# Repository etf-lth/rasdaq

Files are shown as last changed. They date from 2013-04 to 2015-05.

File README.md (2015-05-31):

# Rasdaq: Raspberry Pi Data Acquisition

Rasdaq is a 8-channel 16-bit high-speed ADC solution using the Raspberry Pi, with current measurement adapters.
Rasdaq was developed by ETF (The Student’s Association for Applied Electronics at the Faculty of Engineering (LTH), Lund University, Sweden) for
academic research in power efficiency of graphic accelerators (GPUs).

An illustrated introduction is available here: http://etf.nu/projects/rasdaq

User manual and schematics are available in `doc/`.

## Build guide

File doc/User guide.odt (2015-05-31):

Rasdaq Measurement System

by

ETF LTH

v1.0

Hardware

Kit includes:

1. 1x Rasdaq
2. 1x Power supply 5V 2A
3. 1x Power Measurement Adapter
4. 2x Dummy plugs

Rasdaq

The Rasdaq system is based on a Raspberry pi module, with a extension board containing one TI ADS8568 and one Atmega88 for accurate sample rate.

The ADS8568 contains eight 16-bit channels that can be simultaneously sampled at 500Khz with an input swing from -12V to 12V.

Because of restrictions in the Raspberrys non deterministic execution it's not possible to sample at full speed, the maximum sample rate that is stable is 200Khz for 1-8 channels. Higher rates might work but tends to stall the ADC from operating after first run. This might be fixable in software but there are no timetable for this.

The Rasdaq has four connection slots, named A-D each connector has two ad channels connected to it. There is also power supplied in this connector to drive external converters.

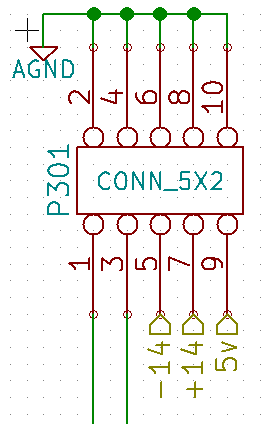
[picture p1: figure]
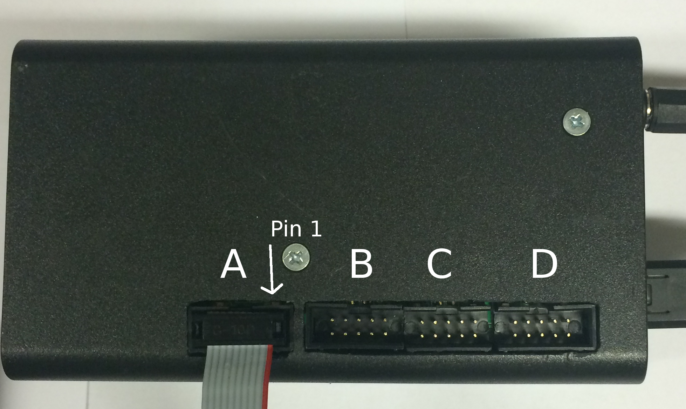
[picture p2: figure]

Power Supply

If this needs to be replaced make sure the polarity of the connector is correct, and that is is of good quality, to large swings in the input voltage might affect the accuracy of the measurements

Positive in center and negative on outer ring.

Power Measurement Adapter

This box connects to the rasdaq and use two channel to measure both the current and the voltage.

It measures the current by using a small resistor (0.05ohm) and amplifies the voltage drop 50 times.

Warning: The plug to Tablet need to be positioned the right way, RED to RED. Failure to do this might destroy the battery.

The connector is polarized so that it should only fit in one way but the leads might still touch if it's tested.

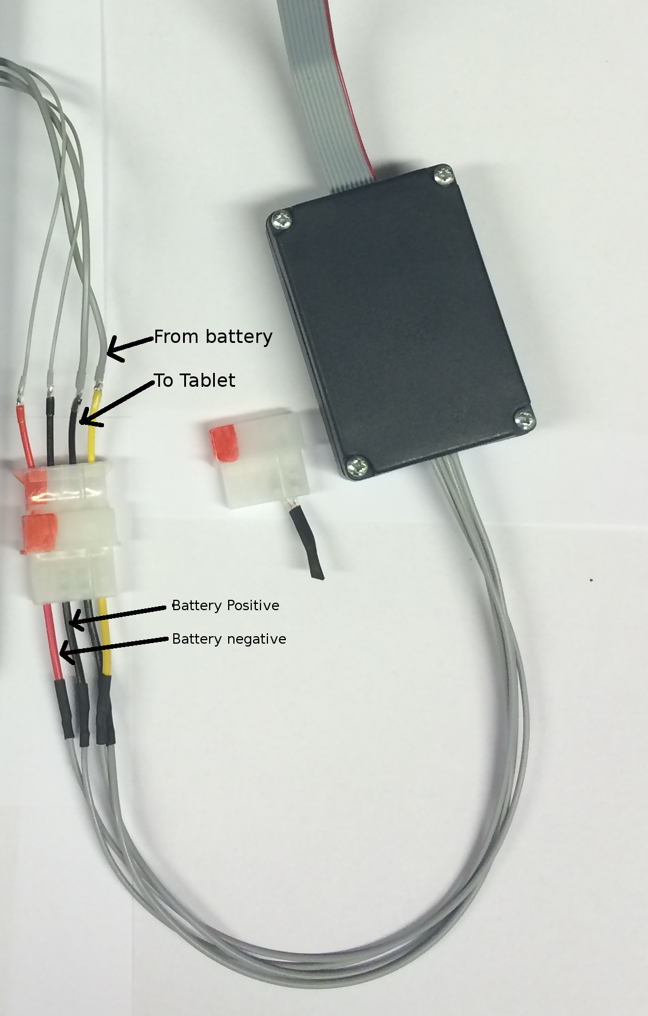
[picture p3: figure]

Dummy plugs

Measuring the current requires the path from the battery to the tablet to be broken, this means the the tablet only function when connected to the Rasdaq.

By using the dummy plugs the connection is made again and the tablet can be used as normal.

This plug is also useful when charging the tablets.

Warning: This plug need to be positioned the right way, RED to RED. Failure to do this might destroy the battery.

The connector is polarized so that it should only fit in one way but the leads might still touch if it's tested.

Software

Rasdaq

The Rasdaq connects through Ethernet and expects to get an IP address from DHCP. To start and downloading measurements SSH is used.

Log on to the rasdaq with

User: root

Password: toor

For doing measurements run the program rdqtool

# rdqtool -h

rdqtool (c) Fredrik Ahlberg, 2013 <fredrik@etf.nu>

Options: -q quiet

-c[n] number of channels, 1..8, default: 8

-r[fs] sample rate in Hz, 1..500000, default: 10000

-b[n] maximum buffer size in tuples, 1..8192

-o[fn] output filename, default: stdout

-n[ns] Stop after n samples, default: run forever

This gives a number of choices on how to to the measurements.

The most important parts are number of channels, sample rate an output filename.

The channels are divided as following

Slot A CH 1,2

Slot B CH 3.4

Slot C CH 5,6

Slot D CH 7.8

Number of channels always starts from channel 1 and forward. It is for example not possible to only sample CH 8.

Example:

rdqtool -c 2 -r 100000 -o test.bin -n 10000

Samples takes 10000 samples in 100Khz from CH 1,2 and saves it to the file test.bin

It is recommended to save the measurements to the internal memory and then download the file as the Raspberry have limited Ethernet capability while it's running the ADC

Computer

The files created from the Rasdaq save the samples as signed 16-bit in the channel sequence.

So for two channels the file looks as following.

CH1_1,CH2_1, CH1_2,CH2_2 and so on.

Example octave script to plot the measured Current and Voltage

fid = fopen('test.bin');
% Open file

adc = fread(fid, [2, inf], '*int16');
% Read file with 2 Channels

fclose(fid);

% sample rate [Hz]

fs = 100000.0;

% calculate number of samples read

samples = size(adc, 2);

% create time vector

t = linspace(0, samples/fs, samples);

% recalculate raw readings as voltage.

% the preamplifiers invert the measured voltages.

adc = double(adc);

adc = -adc * 12.0/32768.0;

% calculate current from voltage (shut resistance = 50 mohm, 0.05% tol, 50 V/V gain)

ch0 = adc(1, :) / (0.05 * 50);

% battery voltage on channel 1

ch1 = adc(2, :);

% apply a low-pass filter at 1kHz

fc = 1000.0;

[b,a] = butter(2, fc/fs);

ch0 = filter(b, a, ch0);

ch1 = filter(b, a, ch1);

% calculate power

ptot = ch0 .* ch1;

% plot

close all

clf

figure(1)

hold on

plot(t, ch1, 'r')

plot(t, ch0, 'g')

plot(t, ptot, 'b')

xlabel('Time [s]')

legend('Battery Voltage [V]', 'Battery Current [A]', 'Power [W]')

Taking samples

1. Connect Rasdaq to Ethernet
2. Connect power measurement box
3. Connect Tablet to power measurement box,

Make sure the connector is the correct way, Red to red

4. Use ssh to connect to Rasdaq and start taking samples
5. Start demo on Tablet
6. When demo done stop program on Rasdaq and download data.

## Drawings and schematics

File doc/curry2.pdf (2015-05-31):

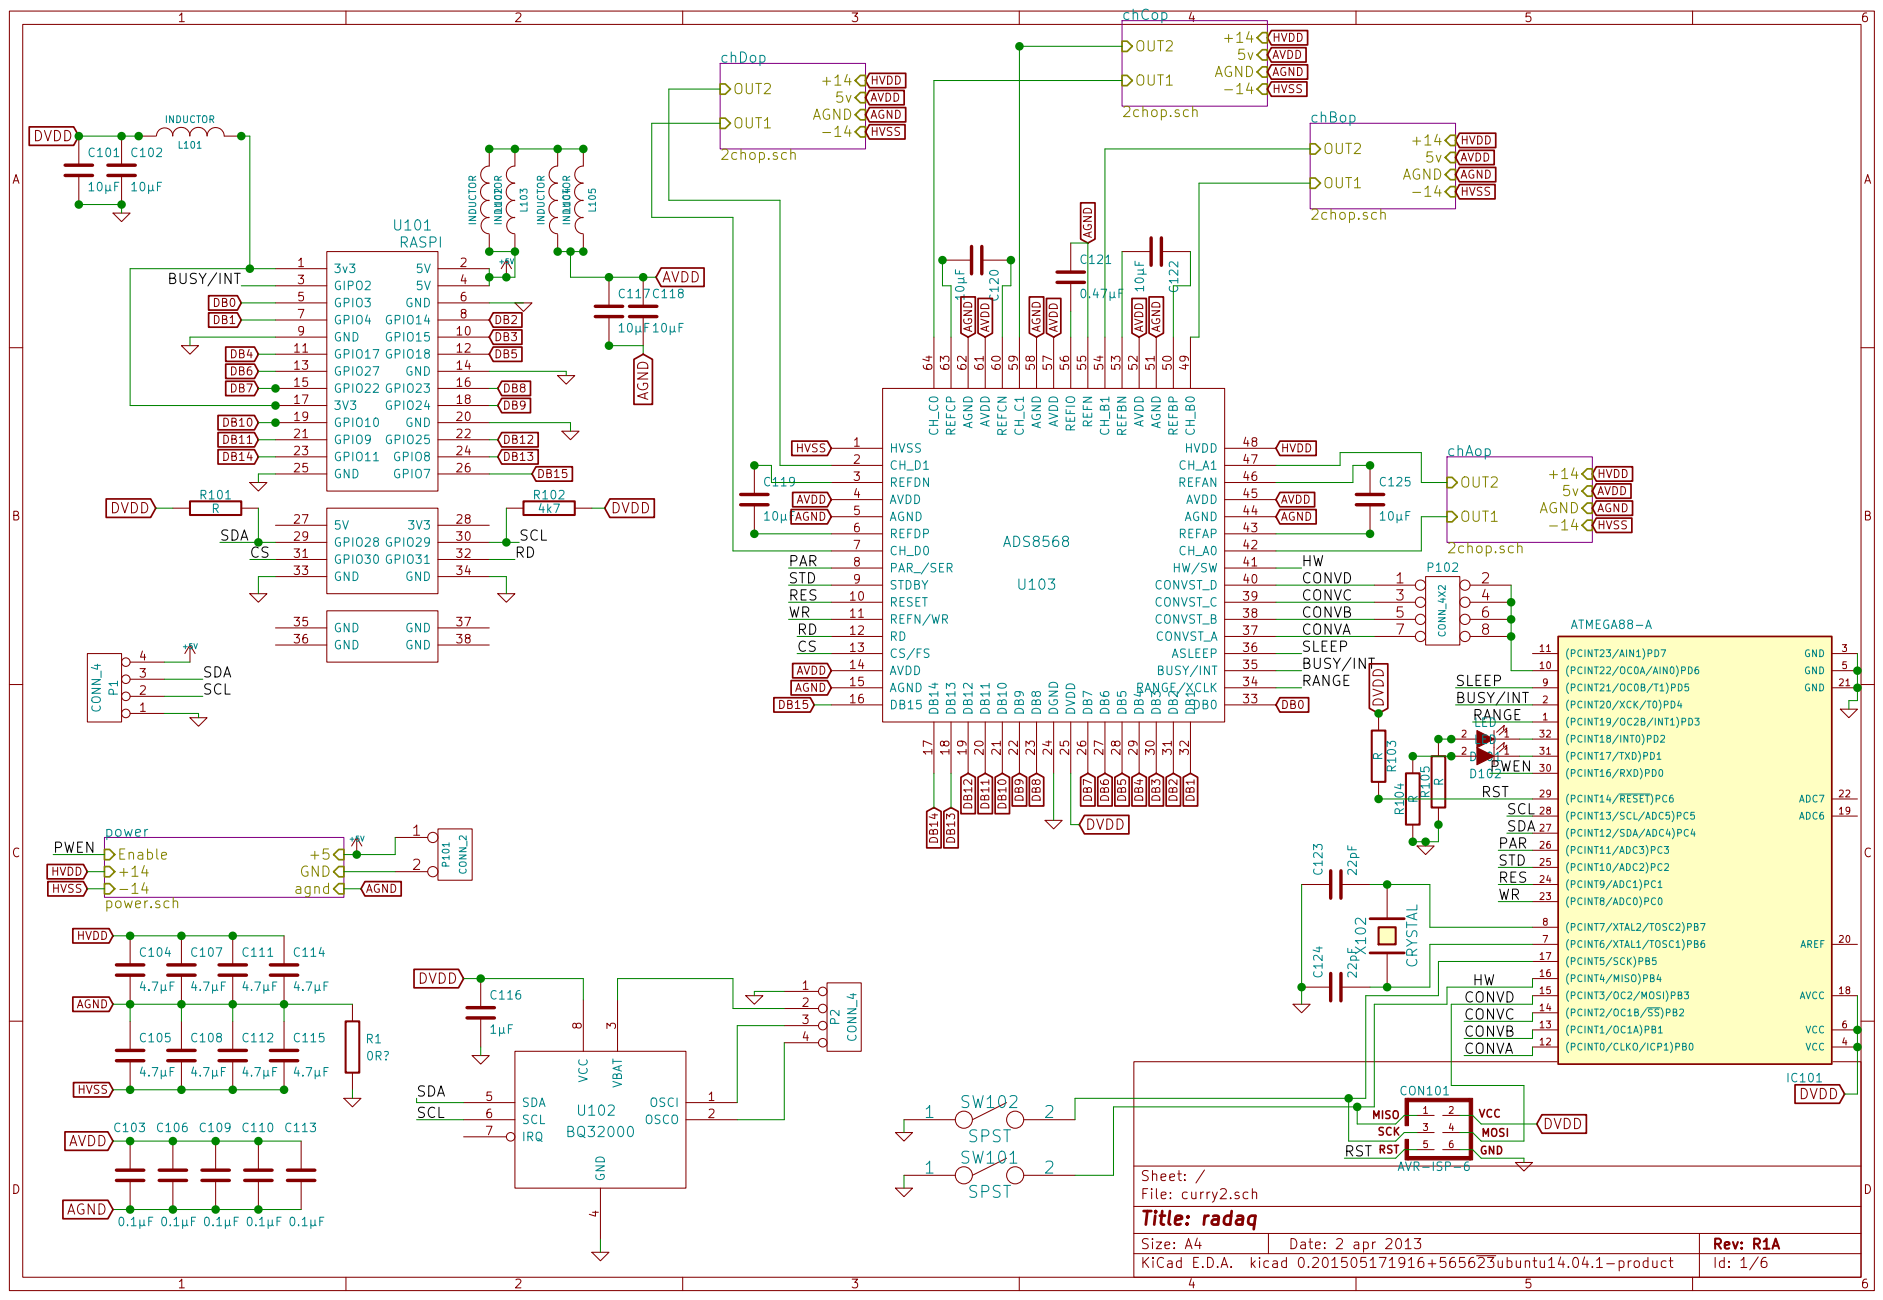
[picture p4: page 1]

10µF power power.sch Enable +14

CONVC 3 | 4
CONVB 5 | 6
CONVA 7 | 8

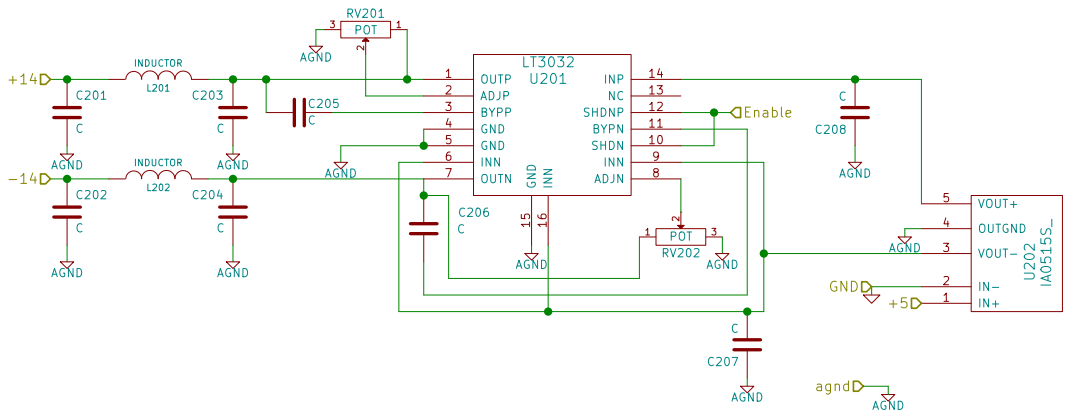
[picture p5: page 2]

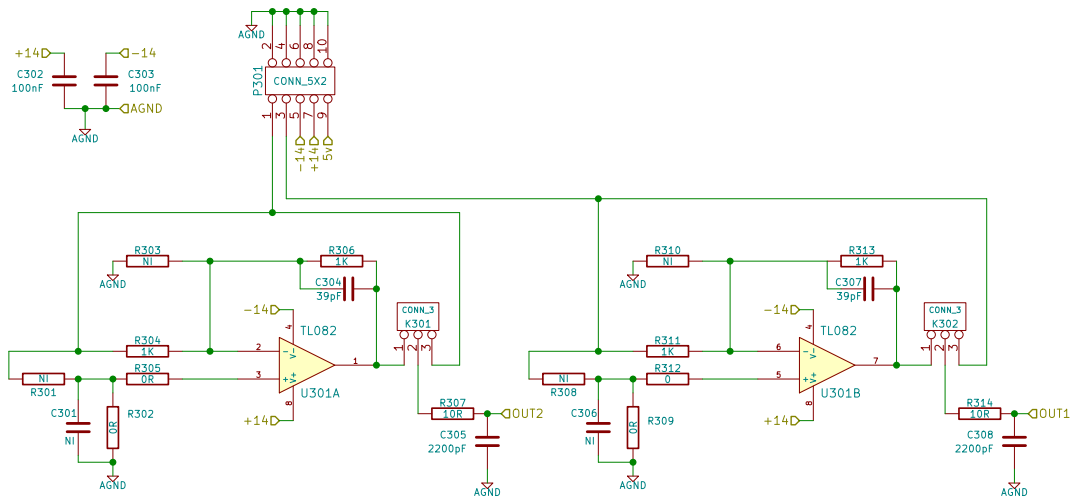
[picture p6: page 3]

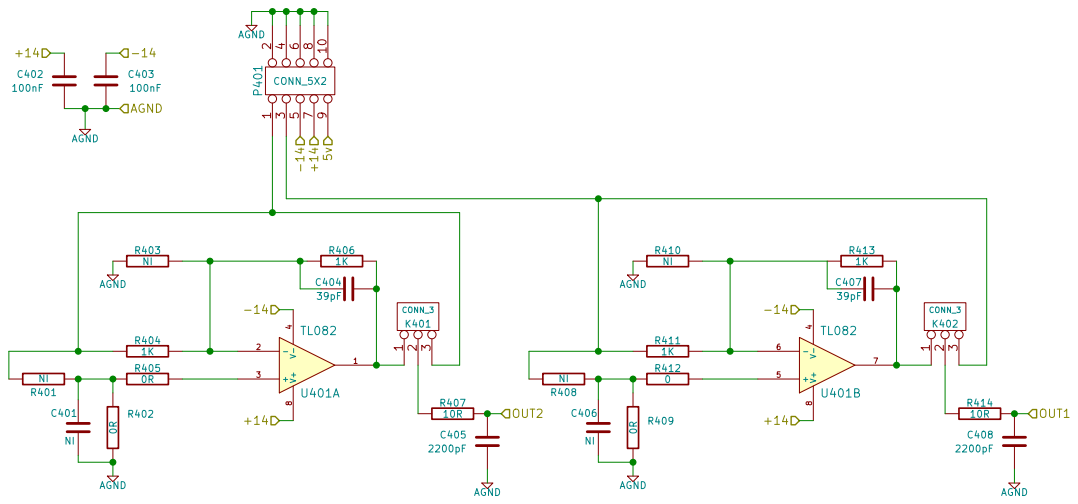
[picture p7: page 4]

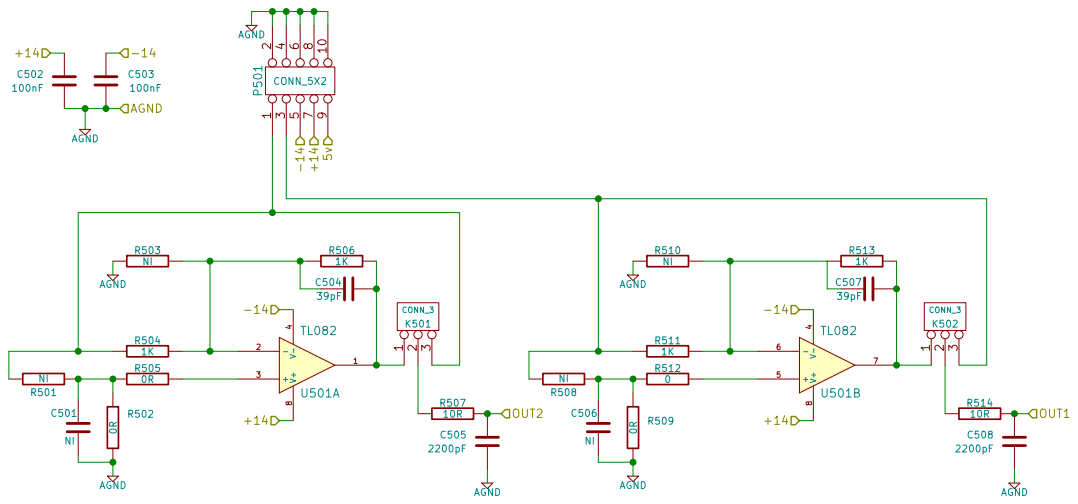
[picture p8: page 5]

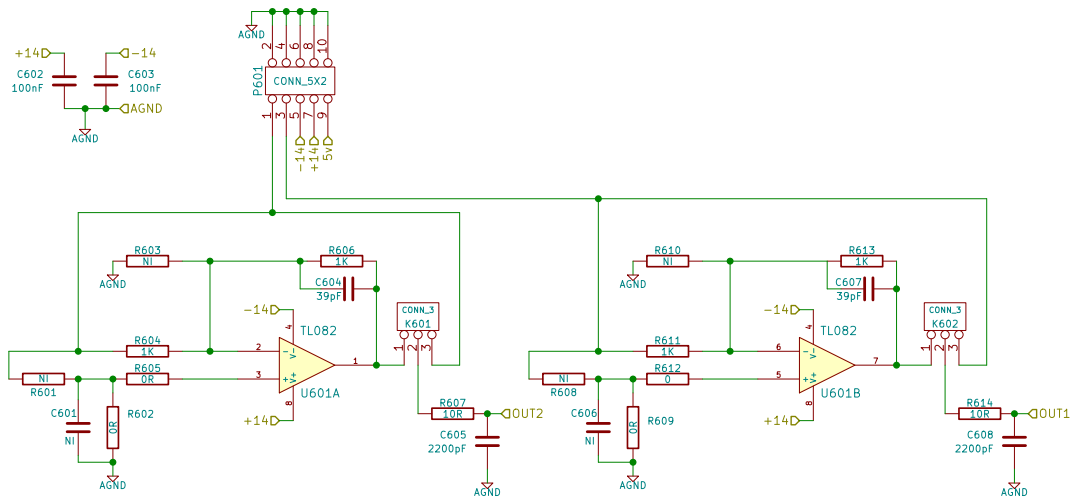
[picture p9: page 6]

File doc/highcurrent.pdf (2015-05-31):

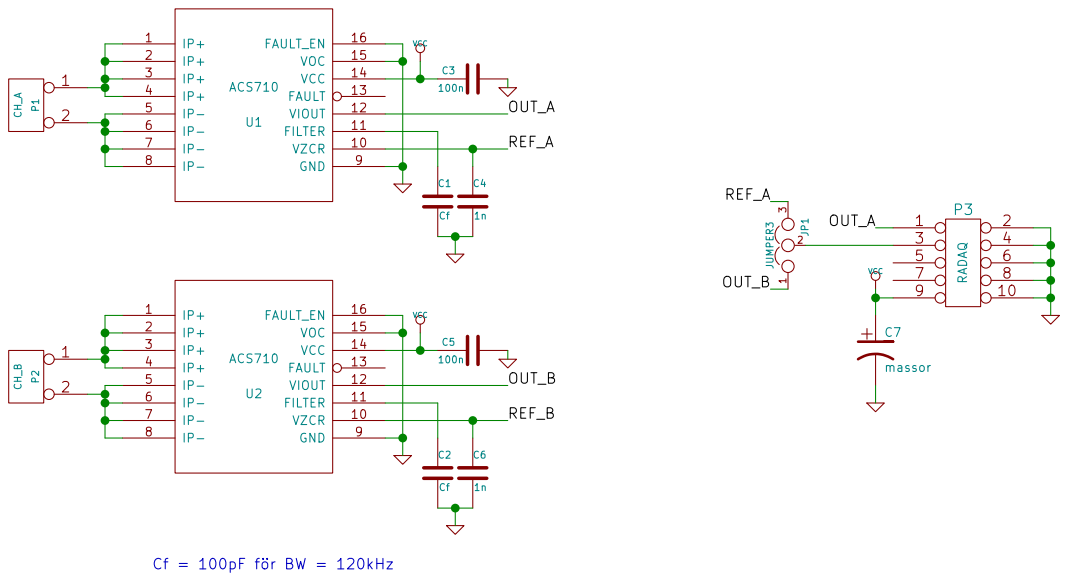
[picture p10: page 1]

File: highcurrent.sch Sheet: /
Id: 1/1 Title: High-current Sensor

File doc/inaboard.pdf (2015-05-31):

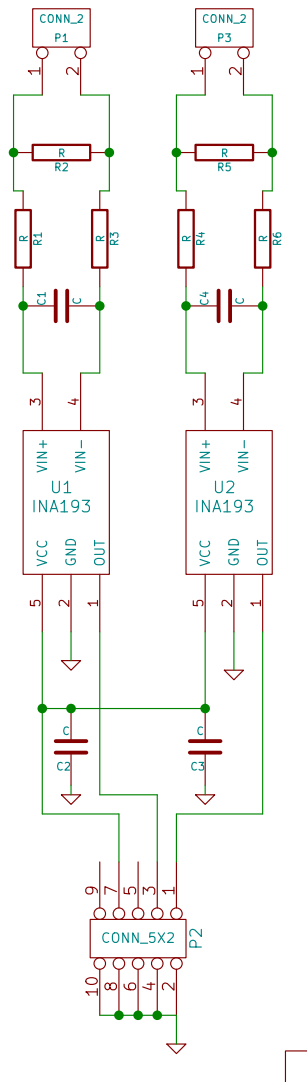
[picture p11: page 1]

1 GND
Id: 1/1 Title: File: inaboard.sch Sheet: / OUT

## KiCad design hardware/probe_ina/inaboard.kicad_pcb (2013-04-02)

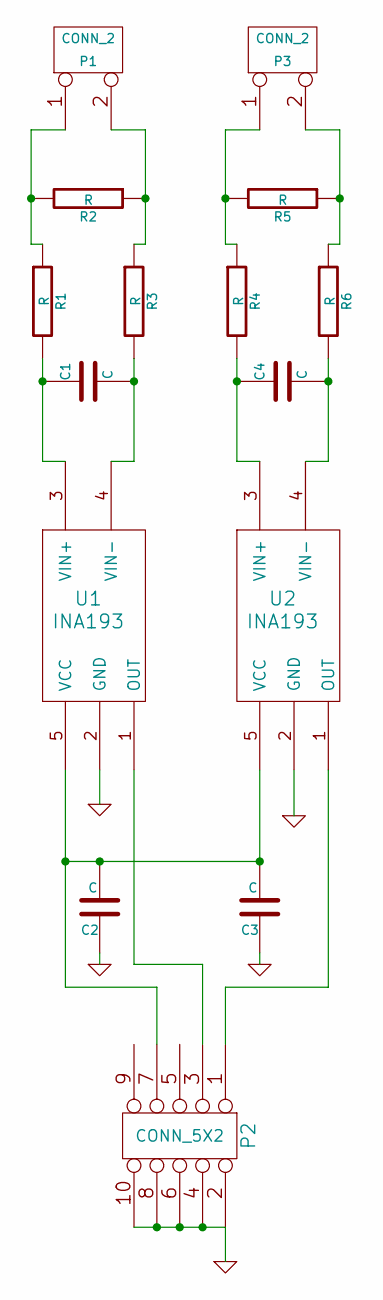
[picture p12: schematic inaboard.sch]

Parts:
C1, C2, C3, C4: C
P1, P3: CONN_2
P2: CONN_5X2
R1, R2, R3, R4, R5, R6: R
U1, U2: INA193

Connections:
GND: C2.1, C3.1, P2.2, P2.4, P2.6, P2.8, P2.10, U1.2 (GND), U2.2 (GND)
unnamed: C2.2, C3.2, P2.7, U1.5 (VCC), U2.5 (VCC)
unnamed: C4.1, R4.2, U2.3 (VIN+)
unnamed: P2.3, U1.1 (OUT)
unnamed: P2.1, U2.1 (OUT)
unnamed: P3.1, R4.1, R5.2
unnamed: P1.1, R1.1, R2.2
unnamed: P1.2 (PM), R2.1, R3.1
unnamed: P3.2 (PM), R5.1, R6.1
unnamed: C1.2, R3.2, U1.4 (VIN-)
unnamed: C1.1, R1.2, U1.3 (VIN+)
unnamed: C4.2, R6.2, U2.4 (VIN-)

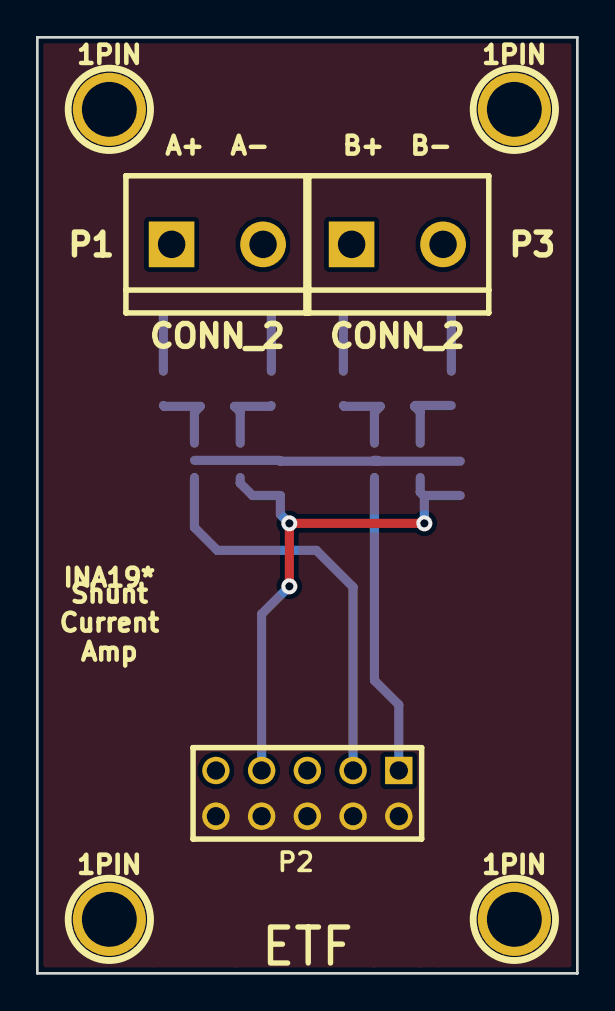
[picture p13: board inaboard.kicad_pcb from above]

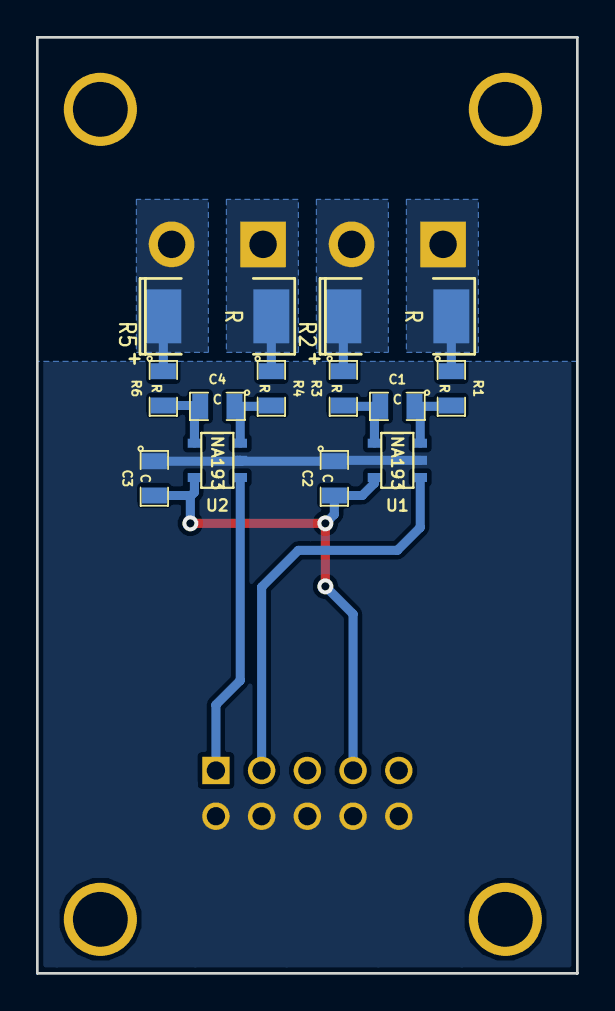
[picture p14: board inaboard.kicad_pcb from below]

Board: 2 copper layers, 30.0 x 52.0 mm, 19 parts (12 on the bottom side), 12 nets.

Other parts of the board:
1PIN, 1PIN#2, 1PIN#3, 1PIN#4: P***; 1pin

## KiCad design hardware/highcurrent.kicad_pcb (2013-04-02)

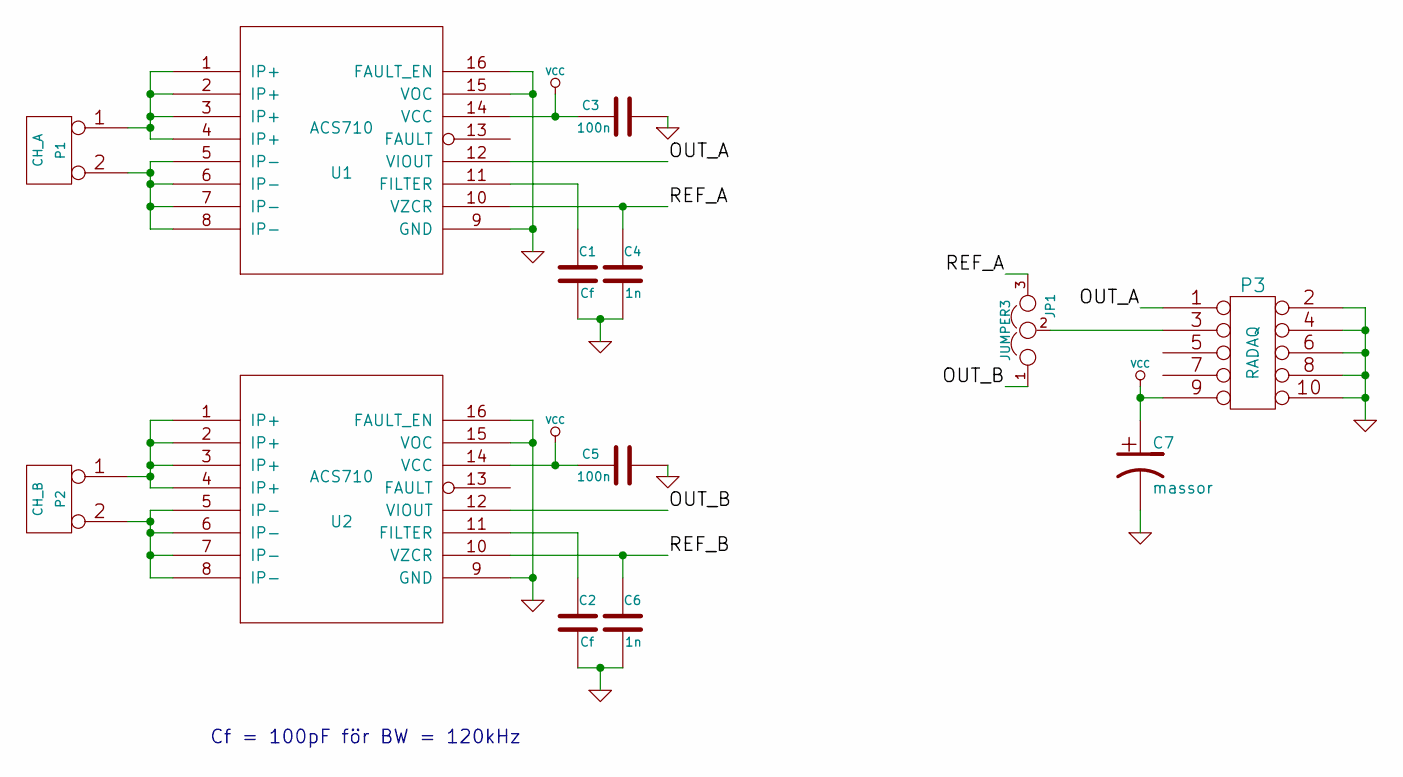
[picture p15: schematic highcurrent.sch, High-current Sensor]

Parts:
C1, C2: Cf
C3, C5: 100n
C4, C6: 1n
C7: massor
JP1: JUMPER3
P1: CH_A
P2: CH_B
P3: RADAQ
U1, U2: ACS710; MODULE

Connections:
/OUT_A: P3.1, U1.12 (VIOUT)
/OUT_B: JP1.1, U2.12 (VIOUT)
/REF_A: C4.1, JP1.3, U1.10 (VZCR)
/REF_B: C6.1, U2.10 (VZCR)
GND: C1.2, C2.2, C3.2, C4.2, C5.2, C6.2, C7.2, P3.2, P3.4, P3.6, P3.8, P3.10, U1.9 (GND), U1.15 (VOC), U1.16 (FAULT_EN), U2.9 (GND), U2.15 (VOC), U2.16 (FAULT_EN)
unnamed: C1.1, U1.11 (FILTER)
unnamed: JP1.2, P3.3
unnamed: C2.1, U2.11 (FILTER)
unnamed: P1.2 (PM), U1.5 (IP-), U1.6 (IP-), U1.7 (IP-), U1.8 (IP-)
unnamed: P1.1, U1.1 (IP+), U1.2 (IP+), U1.3 (IP+), U1.4 (IP+)
unnamed: P2.1, U2.1 (IP+), U2.2 (IP+), U2.3 (IP+), U2.4 (IP+)
unnamed: P2.2 (PM), U2.5 (IP-), U2.6 (IP-), U2.7 (IP-), U2.8 (IP-)
VCC: C3.1, C5.1, C7.1, P3.9, U1.14 (VCC), U2.14 (VCC)

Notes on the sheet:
Cf = 100pF för BW = 120kHz

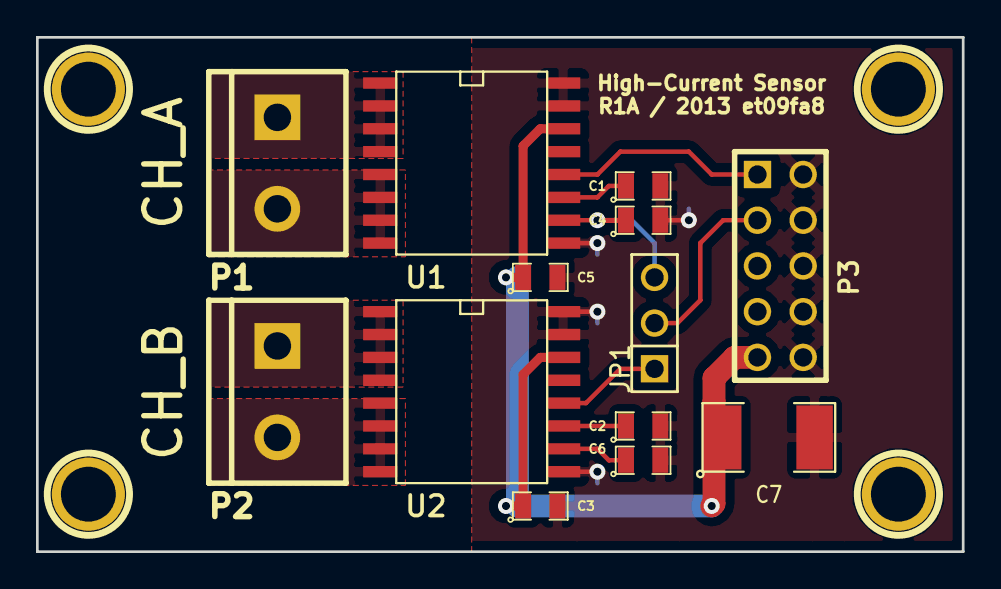
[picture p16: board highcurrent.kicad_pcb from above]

Board: 2 copper layers, 51.4 x 28.6 mm, 17 parts (0 on the bottom side), 13 nets.

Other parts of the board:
1PIN, 1PIN#2, 1PIN#3, 1PIN#4: P***; 1pin

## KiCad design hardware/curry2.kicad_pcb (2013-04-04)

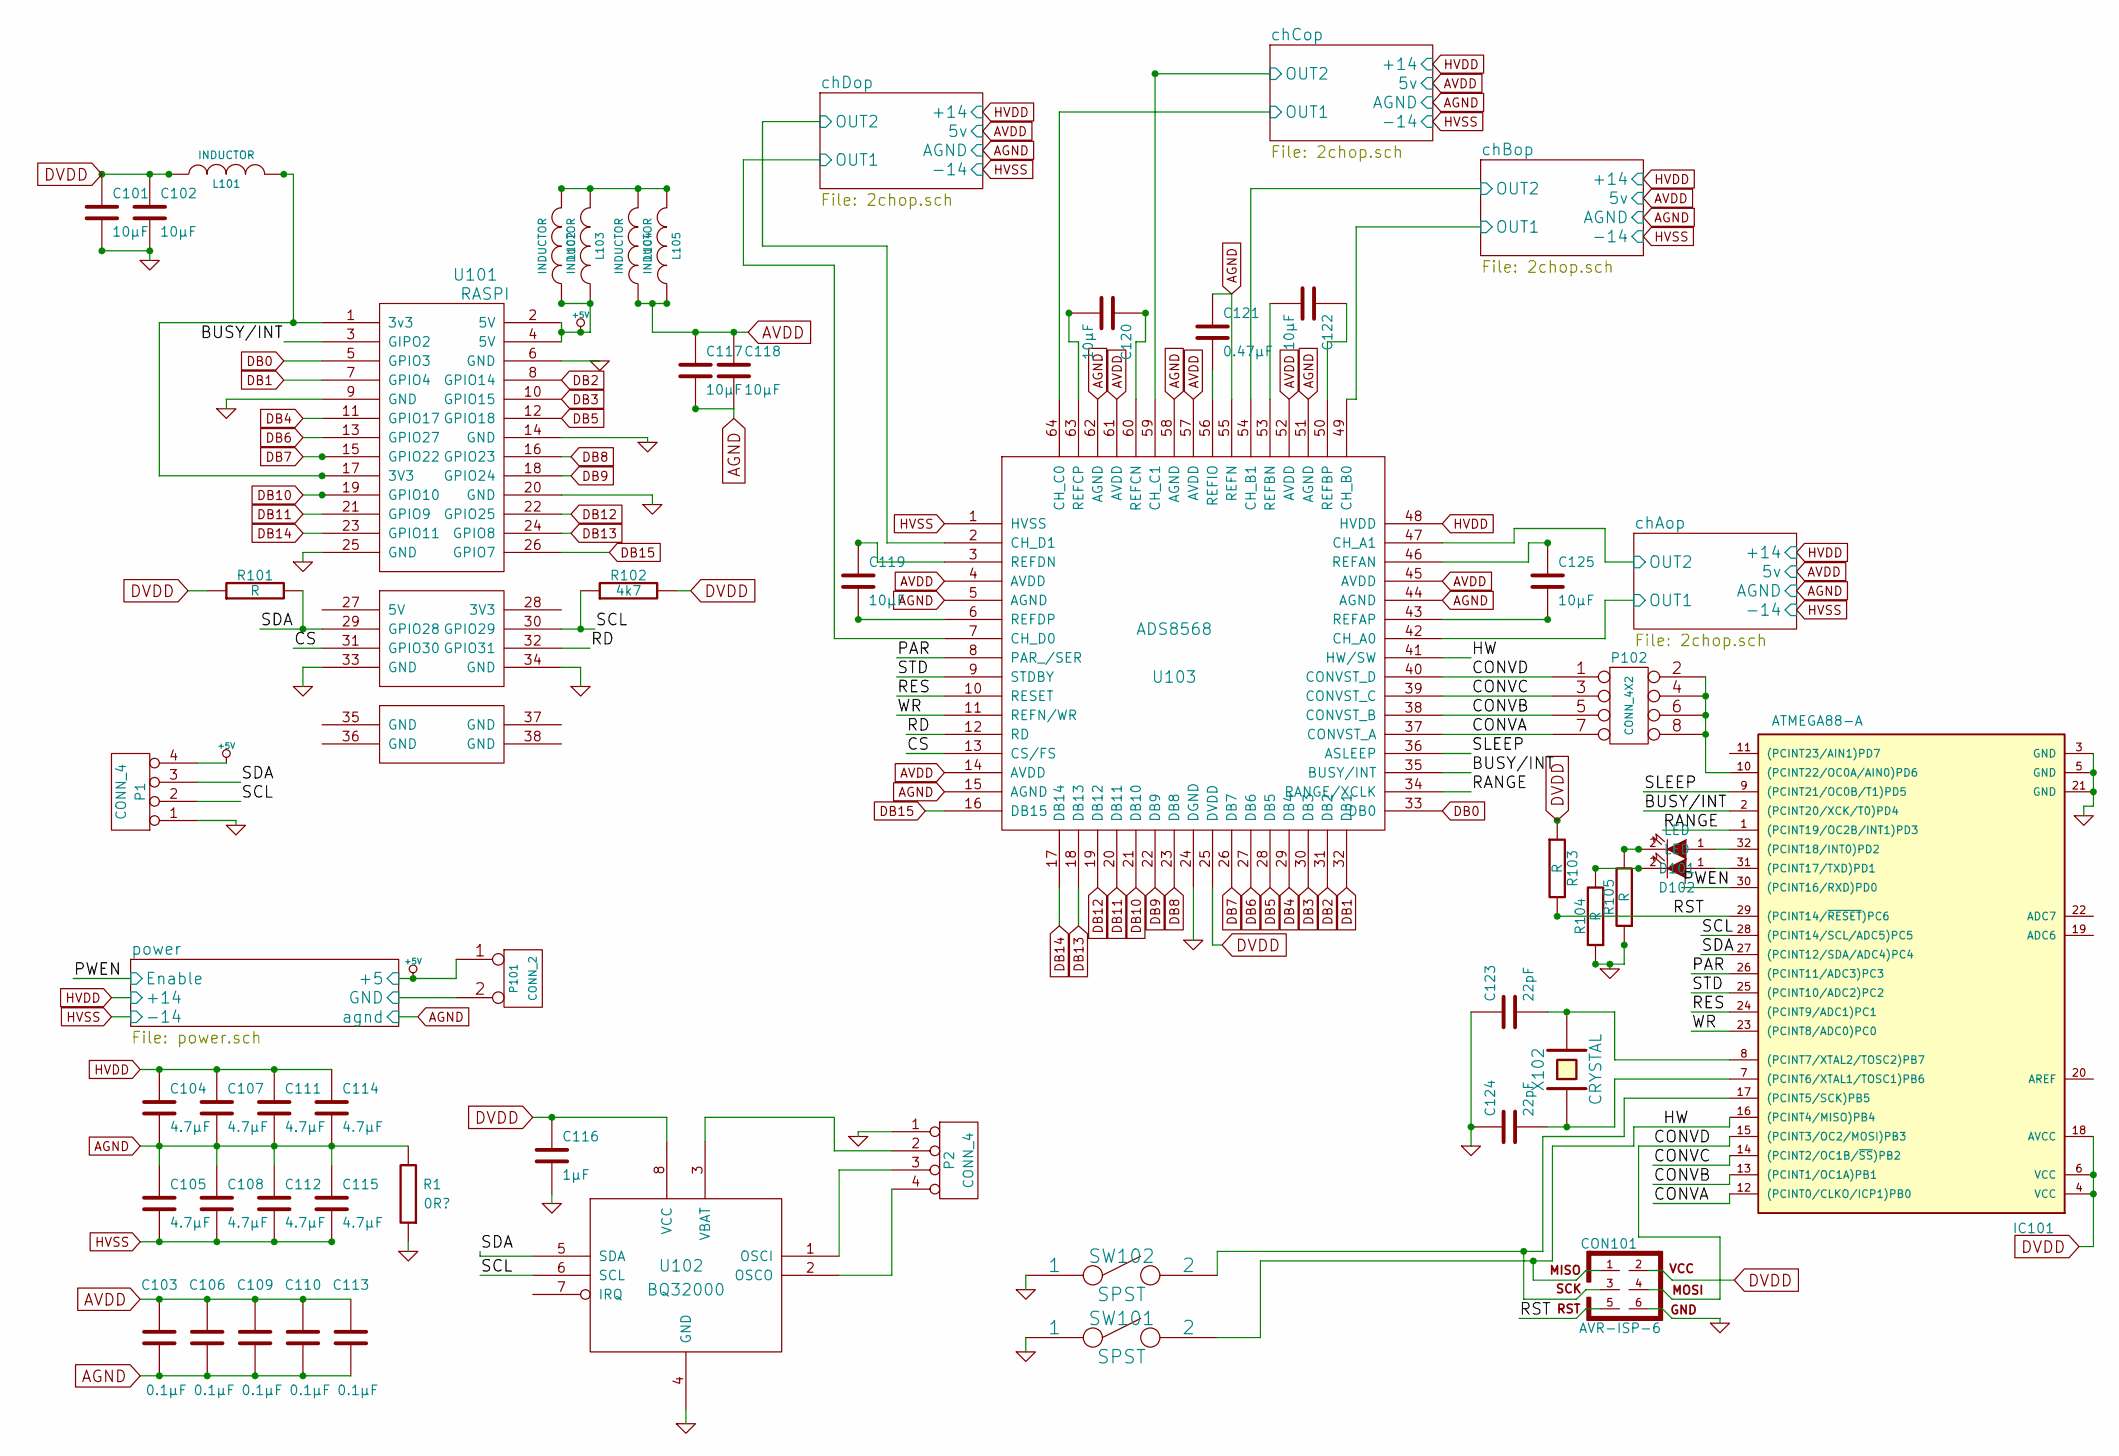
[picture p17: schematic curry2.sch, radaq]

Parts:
C101, C102, C117, C118, C119, C120, C122, C125: 10µF
C103, C106, C109, C110, C113: 0.1µF
C104, C105, C107, C108, C111, C112, C114, C115: 4.7µF
C116: 1µF
C121: 0.47µF
C123, C124: 22pF
CON101: AVR-ISP-6
D101, D102: LED
IC101: ATMEGA88-A; TQFP32
L101, L102, L103, L104, L105: INDUCTOR
P1, P2: CONN_4
P101: CONN_2
P102: CONN_4X2
R1: 0R?
R101, R103, R104, R105: R
R102: 4k7
SW101, SW102: SPST
U101: RASPI
U102: BQ32000
U103: ADS8568
X102: CRYSTAL

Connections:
+5V: L102.1, L103.1, P1.4, P101.1, U101.2 (5V), U101.4 (5V); also elsewhere on the board
/BUSY/INT: IC101.2 ((PCINT20/XCK/T0)PD4), U101.3 (GIPO2), U103.35 (BUSY/INT)
/CONVA: IC101.12 ((PCINT0/CLKO/ICP1)PB0), P102.7, U103.37 (CONVST_A)
/CONVB: IC101.13 ((PCINT1/OC1A)PB1), P102.5, U103.38 (CONVST_B)
/CONVC: IC101.14 ((PCINT2/OC1B/~SS~)PB2), P102.3, U103.39 (CONVST_C)
/CONVD: CON101.4, IC101.15 ((PCINT3/OC2/MOSI)PB3), P102.1, U103.40 (CONVST_D)
/CS: U101.31 (GPIO30), U103.13 (CS/FS)
/HW: CON101.1, IC101.16 ((PCINT4/MISO)PB4), SW101.2, U103.41 (HW/SW)
/PAR: IC101.26 ((PCINT11/ADC3)PC3), U103.8 (PAR_/SER)
/RANGE: IC101.1 ((PCINT19/OC2B/INT1)PD3), U103.34 (RANGE/XCLK)
/RD: U101.32 (GPIO31), U103.12 (RD)
/RES: IC101.24 ((PCINT9/ADC1)PC1), U103.10 (RESET)
/RST: CON101.5, IC101.29 ((PCINT14/~RESET~)PC6), R103.2
/SCL: IC101.28 ((PCINT14/SCL/ADC5)PC5), P1.2, R102.1, U101.30 (GPIO29), U102.6 (SCL)
/SDA: IC101.27 ((PCINT12/SDA/ADC4)PC4), P1.3, R101.2, U101.29 (GPIO28), U102.5 (SDA)
/SLEEP: IC101.9 ((PCINT21/OC0B/T1)PD5), U103.36 (ASLEEP)
/STD: IC101.25 ((PCINT10/ADC2)PC2), U103.9 (STDBY)
/WR: IC101.23 ((PCINT8/ADC0)PC0), U103.11 (REFN/WR)
/chAop/OUT1: U103.42 (CH_A0); also elsewhere on the board
/chAop/OUT2: U103.47 (CH_A1); also elsewhere on the board
/chBop/OUT1: U103.49 (CH_B0); also elsewhere on the board
/chBop/OUT2: U103.54 (CH_B1); also elsewhere on the board
/chCop/OUT1: U103.64 (CH_C0); also elsewhere on the board
/chCop/OUT2: U103.59 (CH_C1); also elsewhere on the board
/chDop/OUT1: U103.7 (CH_D0); also elsewhere on the board
/chDop/OUT2: U103.2 (CH_D1); also elsewhere on the board
/power/Enable: IC101.30 ((PCINT16/RXD)PD0); also elsewhere on the board
AGND: C103.2, C104.2, C105.1, C106.2, C107.2, C108.1, C109.2, C110.2, C111.2, C112.1, C113.2, C114.2, C115.1, C117.2, C118.2, C121.1, R1.2, U103.5 (AGND), U103.15 (AGND), U103.44 (AGND), U103.51 (AGND), U103.55 (REFN), U103.58 (AGND), U103.62 (AGND); also elsewhere on the board
AVDD: C103.1, C106.1, C109.1, C110.1, C113.1, C117.1, C118.1, L104.1, L105.1, U103.4 (AVDD), U103.14 (AVDD), U103.45 (AVDD), U103.52 (AVDD), U103.57 (AVDD), U103.61 (AVDD); also elsewhere on the board
DB0: U101.5 (GPIO3), U103.33 (DB0)
DB1: U101.7 (GPIO4), U103.32 (DB1)
DB2: U101.8 (GPIO14), U103.31 (DB2)
DB3: U101.10 (GPIO15), U103.30 (DB3)
DB4: U101.11 (GPIO17), U103.29 (DB4)
DB5: U101.12 (GPIO18), U103.28 (DB5)
DB6: U101.13 (GPIO27), U103.27 (DB6)
DB7: U101.15 (GPIO22), U103.26 (DB7)
DB8: U101.16 (GPIO23), U103.23 (DB8)
DB9: U101.18 (GPIO24), U103.22 (DB9)
DB10: U101.19 (GPIO10), U103.21 (DB10)
DB11: U101.21 (GPIO9), U103.20 (DB11)
DB12: U101.22 (GPIO25), U103.19 (DB12)
DB13: U101.24 (GPIO8), U103.18 (DB13)
DB14: U101.23 (GPIO11), U103.17 (DB14)
DB15: U101.26 (GPIO7), U103.16 (DB15)
DVDD: C101.1, C102.1, C116.1, CON101.2, IC101.4 (VCC), IC101.6 (VCC), IC101.18 (AVCC), L101.1, R101.1, R102.2, R103.1, U102.8 (VCC), U103.25 (DVDD)
GND: C101.2, C102.2, C116.2, C123.1, C124.1, CON101.6, IC101.3 (GND), IC101.5 (GND), IC101.21 (GND), P1.1, P2.1, P101.2 (PM), R1.1, R104.1, R105.1, SW101.1, SW102.1, U101.6 (GND), U101.9 (GND), U101.14 (GND), U101.20 (GND), U101.25 (GND), U101.33 (GND), U101.34 (GND), U102.4 (GND), U103.24 (DGND); also elsewhere on the board
HVDD: C104.1, C107.1, C111.1, C114.1, U103.48 (HVDD); also elsewhere on the board
HVSS: C105.2, C108.2, C112.2, C115.2, U103.1 (HVSS); also elsewhere on the board
unnamed: C121.2, U103.56 (REFIO)
unnamed: L101.2, U101.1 (3v3), U101.17 (3V3)
unnamed: C125.2, U103.43 (REFAP)
unnamed: C125.1, U103.46 (REFAN)
unnamed: C119.1, U103.3 (REFDN)
unnamed: C119.2, U103.6 (REFDP)
unnamed: C120.2, U103.63 (REFCP)
unnamed: C120.1, U103.60 (REFCN)
unnamed: C122.2, U103.53 (REFBN)
unnamed: C122.1, U103.50 (REFBP)
unnamed: CON101.3, IC101.17 ((PCINT5/SCK)PB5), SW102.2
unnamed: P2.3, U102.1 (OSCI)
unnamed: P2.4, U102.2 (OSCO)
unnamed: P2.2, U102.3 (VBAT)
unnamed: D101.2 (K), R105.2
unnamed: D102.2 (K), R104.2
unnamed: D101.1 (A), IC101.32 ((PCINT18/INT0)PD2)
unnamed: D102.1 (A), IC101.31 ((PCINT17/TXD)PD1)
unnamed: IC101.10 ((PCINT22/OC0A/AIN0)PD6), P102.2, P102.4, P102.6, P102.8
unnamed: L102.2, L103.2, L104.2, L105.2
unnamed: C124.2, IC101.7 ((PCINT6/XTAL1/TOSC1)PB6), X102.1
unnamed: C123.2, IC101.8 ((PCINT7/XTAL2/TOSC2)PB7), X102.2

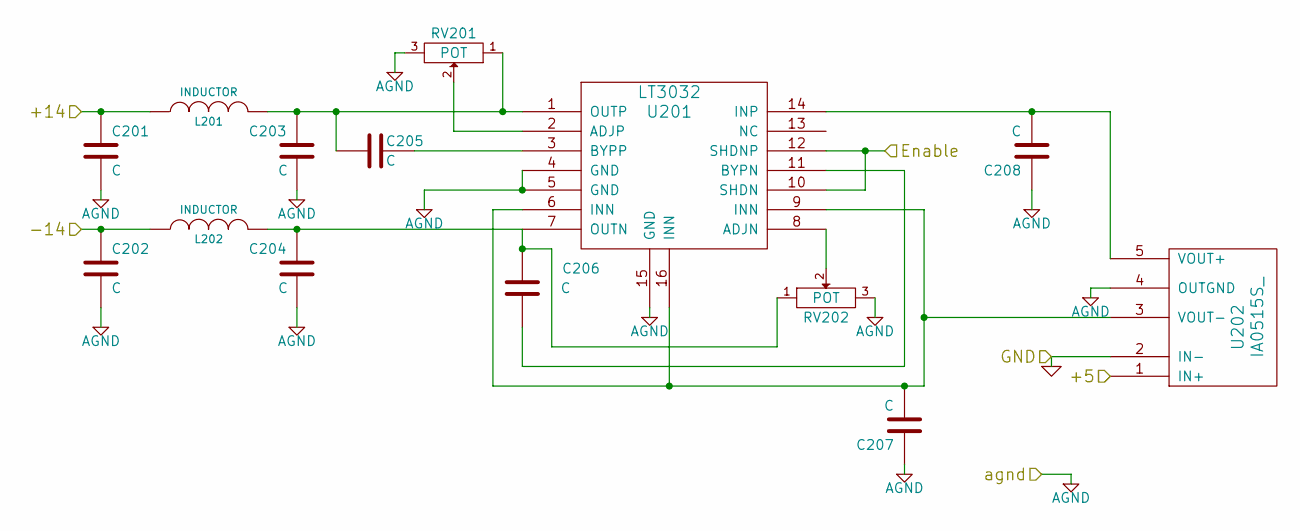
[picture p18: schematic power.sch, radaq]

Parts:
C201, C202, C203, C204, C205, C206, C207, C208: C
L201, L202: INDUCTOR
RV201, RV202: POT
U201: LT3032
U202: IA0515S_

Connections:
+5V: U202.1 (IN+); also elsewhere on the board
/power/Enable: U201.10 (SHDN), U201.12 (SHDNP); also elsewhere on the board
AGND: C201.2, C202.2, C203.2, C204.2, C207.1, C208.1, RV201.3, RV202.3, U201.4 (GND), U201.5 (GND), U201.15 (GND), U202.4 (OUTGND); also elsewhere on the board
GND: U202.2 (IN-); also elsewhere on the board
HVDD: C201.1, L201.1; also elsewhere on the board
HVSS: C202.1, L202.1; also elsewhere on the board
unnamed: C205.1, U201.3 (BYPP)
unnamed: C207.2, U201.6 (INN), U201.9 (INN), U201.16 (INN), U202.3 (VOUT-)
unnamed: C208.2, U201.14 (INP), U202.5 (VOUT+)
unnamed: RV202.2, U201.8 (ADJN)
unnamed: RV201.2, U201.2 (ADJP)
unnamed: C206.1, U201.11 (BYPN)
unnamed: C204.1, C206.2, L202.2, RV202.1, U201.7 (OUTN)
unnamed: C203.1, C205.2, L201.2, RV201.1, U201.1 (OUTP)

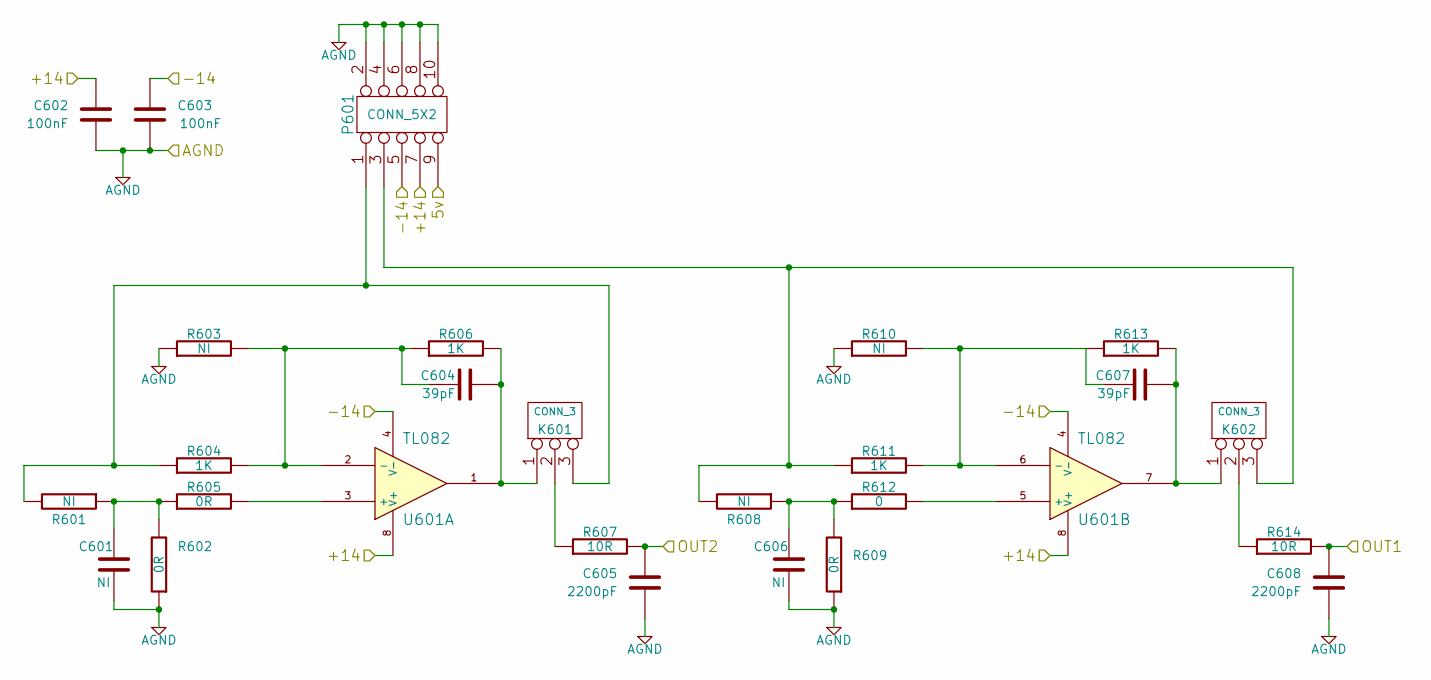
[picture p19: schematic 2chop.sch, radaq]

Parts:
C301, C306: NI
C302, C303: 100nF
C304, C307: 39pF
C305, C308: 2200pF
K301, K302: CONN_3
P301: CONN_5X2
R301, R303, R308, R310: NI
R302, R305, R309: 0R
R304, R306, R311, R313: 1K
R307, R314: 10R
R312: 0
U301: TL082

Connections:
/chAop/OUT1: C308.2, R314.2; also elsewhere on the board
/chAop/OUT2: C305.2, R307.2; also elsewhere on the board
AGND: C301.2, C302.1, C303.1, C305.1, C306.2, C308.1, P301.2, P301.4, P301.6, P301.8, P301.10, R302.1, R303.1, R309.1, R310.1; also elsewhere on the board
AVDD: P301.9; also elsewhere on the board
HVDD: C302.2, P301.7, U301.8 (V+); also elsewhere on the board
HVSS: C303.2, P301.5, U301.4 (V-); also elsewhere on the board
unnamed: C307.2, K302.1, R313.2, U301.7
unnamed: R312.2, U301.5 (+)
unnamed: C307.1, R310.2, R311.2, R313.1, U301.6 (-)
unnamed: K301.2 (PM), R307.1
unnamed: R305.2, U301.3 (+)
unnamed: C306.1, R308.1, R309.2, R312.1
unnamed: C301.1, R301.1, R302.2, R305.1
unnamed: K302.3, P301.3, R308.2, R311.1
unnamed: K302.2 (PM), R314.1
unnamed: C304.2, K301.1, R306.2, U301.1
unnamed: C304.1, R303.2, R304.2, R306.1, U301.2 (-)
unnamed: K301.3, P301.1, R301.2, R304.1

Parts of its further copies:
C401, C406, C501, C506, C601, C606: NI
C402, C403, C502, C503, C602, C603: 100nF
C404, C407, C504, C507, C604, C607: 39pF
C405, C408, C505, C508, C605, C608: 2200pF
K401, K402, K501, K502, K601, K602: CONN_3
P401, P501, P601: CONN_5X2
R401, R403, R408, R410, R501, R503, R508, R510, R601, R603, R608, R610: NI
R402, R405, R409, R502, R505, R509, R602, R605, R609: 0R
R404, R406, R411, R413, R504, R506, R511, R513, R604, R606, R611, R613: 1K
R407, R414, R507, R514, R607, R614: 10R
R412, R512, R612: 0
U401, U501, U601: TL082

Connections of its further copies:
/chBop/OUT1: C408.2, R414.2; also elsewhere on the board
/chBop/OUT2: C405.2, R407.2; also elsewhere on the board
/chCop/OUT1: C508.2, R514.2; also elsewhere on the board
/chCop/OUT2: C505.2, R507.2; also elsewhere on the board
/chDop/OUT1: C608.2, R614.2; also elsewhere on the board
/chDop/OUT2: C605.2, R607.2; also elsewhere on the board
AGND: C401.2, C402.1, C403.1, C405.1, C406.2, C408.1, C501.2, C502.1, C503.1, C505.1, C506.2, C508.1, C601.2, C602.1, C603.1, C605.1, C606.2, C608.1, P401.2, P401.4, P401.6, P401.8, P401.10, P501.2, P501.4, P501.6, P501.8, P501.10, P601.2, P601.4, P601.6, P601.8, P601.10, R402.1, R403.1, R409.1, R410.1, R502.1, R503.1, R509.1, R510.1, R602.1, R603.1, R609.1, R610.1; also elsewhere on the board
AVDD: P401.9, P501.9, P601.9; also elsewhere on the board
HVDD: C402.2, C502.2, C602.2, P401.7, P501.7, P601.7, U401.8 (V+), U501.8 (V+), U601.8 (V+); also elsewhere on the board
HVSS: C403.2, C503.2, C603.2, P401.5, P501.5, P601.5, U401.4 (V-), U501.4 (V-), U601.4 (V-); also elsewhere on the board
unnamed: K401.2 (PM), R407.1
unnamed: K401.3, P401.1, R401.2, R404.1
unnamed: K402.2 (PM), R414.1
unnamed: C401.1, R401.1, R402.2, R405.1
unnamed: R405.2, U401.3 (+)
unnamed: K402.3, P401.3, R408.2, R411.1
unnamed: C404.2, K401.1, R406.2, U401.1
unnamed: C404.1, R403.2, R404.2, R406.1, U401.2 (-)
unnamed: R412.2, U401.5 (+)
unnamed: C407.1, R410.2, R411.2, R413.1, U401.6 (-)
unnamed: C406.1, R408.1, R409.2, R412.1
unnamed: C407.2, K402.1, R413.2, U401.7
unnamed: K501.2 (PM), R507.1
unnamed: K501.3, P501.1, R501.2, R504.1
unnamed: C501.1, R501.1, R502.2, R505.1
unnamed: K502.2 (PM), R514.1
unnamed: R505.2, U501.3 (+)
unnamed: K502.3, P501.3, R508.2, R511.1
unnamed: C504.2, K501.1, R506.2, U501.1
unnamed: C504.1, R503.2, R504.2, R506.1, U501.2 (-)
unnamed: R512.2, U501.5 (+)
unnamed: C507.1, R510.2, R511.2, R513.1, U501.6 (-)
unnamed: C506.1, R508.1, R509.2, R512.1
unnamed: C507.2, K502.1, R513.2, U501.7
unnamed: K601.2 (PM), R607.1
unnamed: K601.3, P601.1, R601.2, R604.1
unnamed: K602.2 (PM), R614.1
unnamed: C601.1, R601.1, R602.2, R605.1
unnamed: R605.2, U601.3 (+)
unnamed: K602.3, P601.3, R608.2, R611.1
unnamed: C604.2, K601.1, R606.2, U601.1
unnamed: C604.1, R603.2, R604.2, R606.1, U601.2 (-)
unnamed: R612.2, U601.5 (+)
unnamed: C607.1, R610.2, R611.2, R613.1, U601.6 (-)
unnamed: C606.1, R608.1, R609.2, R612.1
unnamed: C607.2, K602.1, R613.2, U601.7

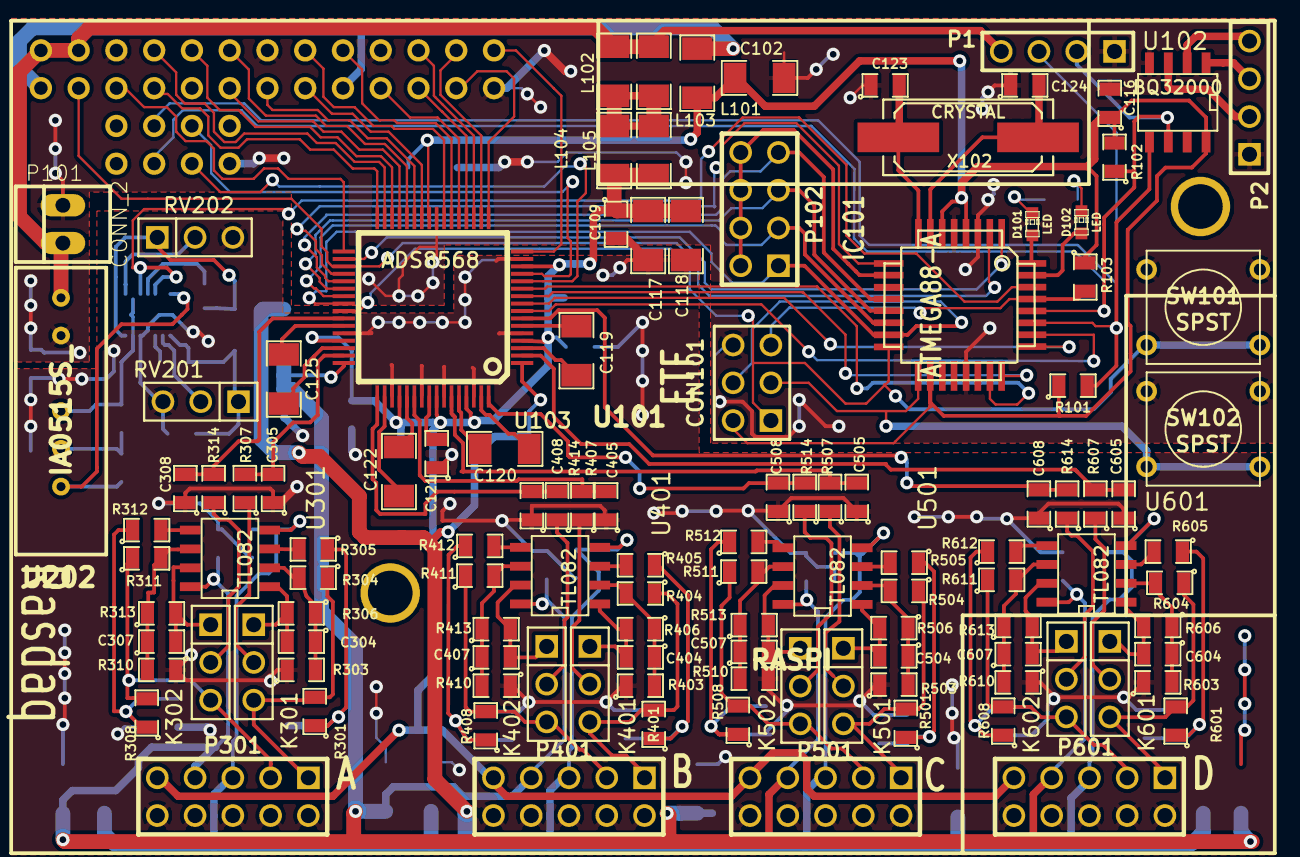
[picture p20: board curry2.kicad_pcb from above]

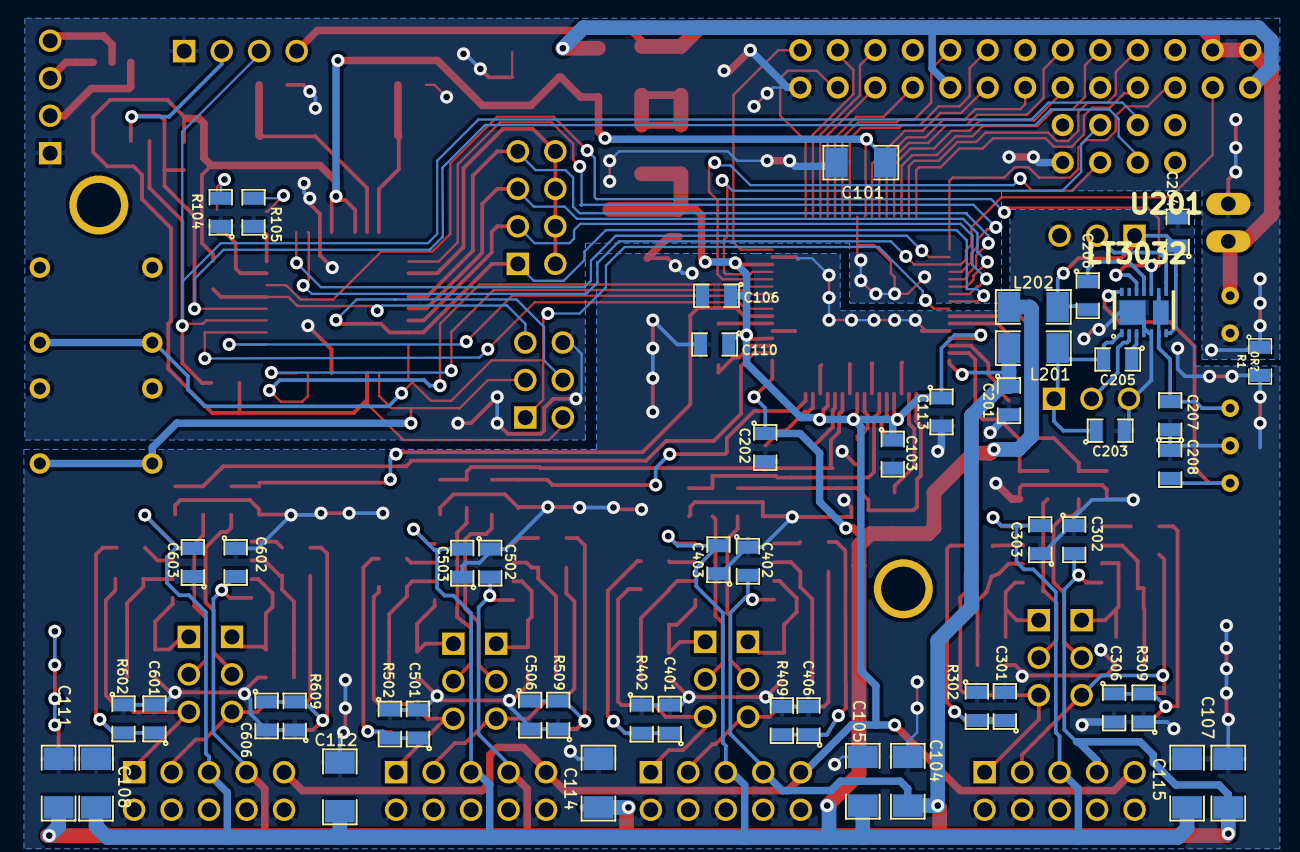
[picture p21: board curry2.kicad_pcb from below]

Board: 2 copper layers, 168 parts (51 on the bottom side), 127 nets.

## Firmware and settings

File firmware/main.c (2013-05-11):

#include <avr/io.h>
#include <avr/interrupt.h>
#include <util/delay.h>
#include <util/twi.h>

#include "board.h"
#include "adc.h"
#include "protocol.h"

uint8_t errorflag = 0;

ISR(TIMER1_COMPA_vect)
{
    adc_startConversion();
}

void cmd_write(uint8_t reg, uint8_t data)
{
    switch (reg) {
    case PROTO_LED: // Set LEDs
        PORTD = (PORTD & ~(_BV(IO_LED1)|_BV(IO_LED2)))
            | (data & 1 ? _BV(IO_LED1) : 0)
            | (data & 2 ? _BV(IO_LED2) : 0);
        break;

    case PROTO_MODE:
        adc_setMode(data);
        break;

    case PROTO_STRB_WR:
        adc_strobeWrite();
        break;

    case PROTO_STRB_RST:
        adc_strobeReset();
        break;

    case PROTO_POWER:
        adc_setPower(data);
        break;

    case PROTO_STANDBY:
        adc_setStandby(data);
        break;

    case PROTO_RANGE:
        adc_setRange(data);
        break;

    case PROTO_STARTCNV:
        adc_startConversion();
        break;

    case PROTO_REFEN:
        adc_setReference(data);
        break;

    /*case PROTO_BURST:
        burst = 1024;
        break;*/

    case PROTO_RUN:
        TCNT1 = 0;      // starta om timern för att undvika för tidig utlösning.
        TIFR1 = 0xff;   // nollställ alla interruptflaggor av samma skäl
        TIMSK1 = data ? _BV(OCIE1A) : 0;
        break;

    case PROTO_FSDIVH:
        OCR1AH = data;
        break;

    case PROTO_FSDIVL:
        OCR1AL = data;
        break;

    default:
        errorflag |= ERROR_INVALID_WRITE;
    }
}

uint8_t cmd_read(uint8_t reg)
{
    switch (reg) {
    case PROTO_VERSION:
        return PROTO_VERSION_BYTE;

    case PROTO_LED: //Get LEDs
        return (PORTD & _BV(IO_LED1) ? 0x01 : 0)
            | (PORTD & _BV(IO_LED2) ? 0x02 : 0);

    case PROTO_MODE:
        return adc_getMode();

    case PROTO_POWER:
        return adc_getPower();

    case PROTO_STANDBY:
        return adc_getStandby();

    case PROTO_RANGE:
        return adc_getRange();

    case PROTO_REFEN:
        return adc_getReference();

    case PROTO_STATUS:
        return errorflag;

    case PROTO_FSDIVH:
        return OCR1AH;

    case PROTO_FSDIVL:
        return OCR1AL;

    default:
        errorflag |= ERROR_INVALID_READ;
        return 0xaa;
    }
}

ISR(TWI_vect)
{
    static uint8_t state, reg;

    switch (TWSR) {
        // Own SLA+R has been received, ACK has been returned
        case TW_ST_SLA_ACK:
            TWDR = cmd_read(reg);
            break;

        // Data byte in TWDR has been transmitted, ACK has been received
        //case TW_ST_DATA_ACK:
            //TWDR = 0x55;
            //TWCR = _BV(TWEN)|_BV(TWIE)|_BV(TWINT)|_BV(TWEA);
            //break;

        // Data byte in TWDR has been transmitted, NACK has been received.
        // i.e. this is the end of the transmission
        //case TW_ST_DATA_NACK:
            //TWCR = _BV(TWEN)|_BV(TWIE)|_BV(TWINT)|_BV(TWEA);
            //break;

        // Own SLA+W has been received, ACK has been returned
        case TW_SR_SLA_ACK: // our address, ack
            state = 0;
            //PORTD |= _BV(5);
            //TWCR = _BV(TWEN)|_BV(TWIE)|_BV(TWINT)|_BV(TWEA);
            //TWDR = 0x33;
            break;

        // Previously adressed with SLA+W, data has been received, ACK has been returned
        case TW_SR_DATA_ACK: // data while addressed, ack
            if (state == 0) {
                reg = TWDR;
                state++;
            } else {
                cmd_write(reg, TWDR);
            }
            //TWDR = 0xcc;
            //TWCR = _BV(TWEN)|_BV(TWIE)|_BV(TWINT)|_BV(TWEA);
            break;

        // A STOP or RESTART condition has been received while addressed
        //case TW_SR_STOP:

        // Something happen! Someone set us up the bomb.
        //default:
        //    TWCR = _BV(TWEN)|_BV(TWIE)|_BV(TWINT)|_BV(TWEA);
    }
    
    TWCR = _BV(TWEN)|_BV(TWIE)|_BV(TWINT)|_BV(TWEA);
}

int main(void)
{
    /* Status LEDs */
    DDRD = _BV(IO_LED1)|_BV(IO_LED2);

    /* I2C to Raspberry */
    TWAR = (3 << 1);
    TWDR = 0xFF;
    TWCR = _BV(TWEN)|_BV(TWIE)|_BV(TWINT)|_BV(TWEA);

    /* Init ADC */
    adc_init();

    /* Internal timekeeping, ~1000Hz */
#if 0
    TCCR0A = _BV(WGM01);
    TCCR0B = _BV(CS02)|_BV(CS00);
    OCR0A = 19;
    TIMSK0 = _BV(OCIE0A);
#endif

    TCCR1A = 0; //_BV(WGM01);
    TCCR1B = _BV(WGM12)|_BV(CS10); // clkio/1
    //OCR0A = 19;
    //TIMSK1 = _BV(OCIE1A);


    /* Go for it! */
    sei();

    while (1) ;
}

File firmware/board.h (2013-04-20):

#ifndef BOARD_H
#define BOARD_H

#define ADC_CONVA   /*PB*/ 0
#define ADC_CONVB   /*PB*/ 1
#define ADC_CONVC   /*PB*/ 2
#define ADC_CONVD   /*PB*/ 3
#define ADC_HWSEL   /*PB*/ 4
#define IO_BUTTON   /*PB*/ 5

#define ADC_WR      /*PC*/ 0
#define ADC_REFEN   /*PC*/ 0
#define ADC_RESET   /*PC*/ 1
#define ADC_STBY    /*PC*/ 2
#define ADC_PARSEL  /*PC*/ 3

#define PSU_PWEN    /*PD*/ 0
#define IO_LED1     /*PD*/ 1
#define IO_LED2     /*PD*/ 2
#define ADC_RANGE   /*PD*/ 3
#define ADC_BUSYINT /*PD*/ 4
#define ADC_SLEEP   /*PD*/ 5
#define ADC_CONVALL /*PD*/ 6

#endif

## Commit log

2013-03-26 Schematic almost done
    [2chop.sch, curry2.sch, power.sch]
2013-03-27 almost done rtc placed
    [2chop.sch, curry2.sch, power.sch]
2013-03-28 fixed all pcb components
    [$curry2.brd, 2chop.sch, curry2.sch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]
2013-03-28 all op is done blaj
    [$curry2.brd, 2chop.sch, curry2.sch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]
2013-04-02 almost done
    [2chop.sch, curry2.kicad_pcb, curry2.sch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]
2013-04-02 städa lite
    [2chop.sch, curry2.kicad_pcb, curry2.sch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]
2013-04-02 almost done pre merger
    [2chop.sch, curry2.kicad_pcb, curry2.sch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]
2013-04-02 pcb done just needs currentsensors
    [2chop.sch, curry2.kicad_pcb, curry2.sch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]
2013-04-02 added highcurrent
    [highcurrent.kicad_pcb, highcurrent.sch]
2013-04-02 added ina board
    [curry2.kicad_pcb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]
2013-04-04 final release pre order
    [curry2.kicad_pcb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]
2013-04-04 ina commit
    [inaboard-B_Cu.gbl, inaboard-B_Mask.gbs, inaboard-B_SilkS.gbo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]
2013-04-04 moved outputs
    [inaboard-B_Cu.gbl, inaboard-B_Mask.gbs, inaboard-B_SilkS.gbo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]
2013-04-04 moved outputfiles
    [inaboard-B_Cu.gbl, inaboard-B_Mask.gbs, inaboard-B_SilkS.gbo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]
2013-04-04 added 10x10
    [10x10.kicadsilk.gto]
2013-04-04 shrunk ina
    [inaboardrotate-B_Cu.gbl, inaboardrotate-B_Mask.gbs, inaboardrotate-B_SilkS.gbo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]
2013-04-04 added high_current gerber
    [highcurrent-B_Cu.gbl, highcurrent-B_Mask.gbs, highcurrent-B_SilkS.gbo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]
2013-04-04 added panel
    [curry2-B_Cu.gbl, curry2-B_Mask.gbs, curry2-B_SilkS.gbo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]
2013-04-23 adc write and read
2013-04-23 adc reset level fix
    [adc.c]
2015-05-31 organized stuff
    [$curry2.brd, 2chop.sch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]
2015-05-31 added pdf schematics
